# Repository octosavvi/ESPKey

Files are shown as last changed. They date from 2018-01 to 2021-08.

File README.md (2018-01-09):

### What the heck is this anyway?
ESPKey is a small device which can be implanted into facility access control systems.  ESPKey is compatible with pretty much every door that requires a card swipe or tap with optional pin code to unlock.  It even works on many systems requiring finger print or other biometric authentication.  Inserting an ESPKey behind a card reader is better than a skimmer because not only can it log all authorized use of a system, it can also inject or replay captured credentials.  Once ESPKey shows you what credentials work on this door, use your favorite RFID tools to clone or simulate those credentials for use on other doors.  Want to show someone how insecure their facility is?  This is an incredibly easy way to start.

In case you need a simple access control system to play with, ESPKey can do that too.  All you need is a card reader, ESPKey and some device to be controlled (like a door lock, electric strike, magnetic lock or just an indicator light).  ESPKey replaces the giant door controller, allowing you to build a simple mobile test lab.  Or a great little portable RFID credential sponge, ready to be hand carried or installed in any heavily trafficked area.

### Releases
Have a look [over here](https://github.com/octosavvi/ESPKey/releases/latest) for the latest pre-built firmware and UI release.

### Build instructions
Open in Arduino IDE and click Verify (or Upload if connected to UART).

### Usage
Check out [this great documentation](https://redteamtools.com/espkey) put together by Babak of Red Team Tools.

### Hardware
Hardware can be [purchased](https://redteamtools.com/espkey) or have a look in the [hardware](hardware/) directory if you want to build your own.

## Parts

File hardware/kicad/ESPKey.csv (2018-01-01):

Source: | ESPKey.sch
Date: | Thu 18 Aug 2016 11:03:30 PM PDT
Tool: | Eeschema 4.1.0-alpha+201607281303+6996~46~ubuntu16.04.1-product
Generator: | /usr/share/doc/kicad/scripts/bom-in-python/bom_csv_grouped_by_value_with_fp.py
Component Count: | 32
Ref | Qnty | Value | Cmp name | Footprint | Description | Vendor
C3, | 1 | np | C | Capacitors_SMD:C_0402 | Unpolarized capacitor
C4, C1, | 2 | 22u | C | Capacitors_SMD:C_0805 | Unpolarized capacitor
C5, C2, | 2 | 100n | C | Capacitors_SMD:C_0603 | Unpolarized capacitor
D1, | 1 | PWR | Led_Small | LEDs:LED_0603 | Led
L1, | 1 | 3.6uH | INDUCTOR_SMALL | Custom_Inductors:ELL4_M-small
P1, | 1 | Power | CONN_2 | Connector_IDC_SMD:SSL_DW_IDC_02
P2, | 1 | Wiegand | CONN_3 | Connector_IDC_SMD:SSL_DW_IDC_03
Q1, Q2, Q3, | 3 | 2N7002 | Q_NMOS_GSD | TO_SOT_Packages_SMD:SOT-23 | Transistor N-MOSFET (general)
R2, R1, | 2 | 75k | R | Resistors_SMD:R_0402 | Resistor
R3, | 1 | 24k | R | Resistors_SMD:R_0402 | Resistor
R6, R4, R5, R7, R8, R9, R10, R12, R13, R15, R16, | 11 | 12k7 | R | Resistors_SMD:R_0402 | Resistor
R11, R14, R17, | 3 | 22k | R | Resistors_SMD:R_0402 | Resistor
R18, | 1 | 330 | R | Resistors_SMD:R_0402 | Resistor
U1, | 1 | RT6212A/B | RT6212A/B | TO_SOT_Packages_SMD:SOT-23-6 | 700 mA Low Dropout Voltage Regulator, Adjustable 3.75V-30V, SO8
U2, | 1 | ESP-12 | ESP-12 | ESP8266:ESP-12-SMD | ESP8622 ESP-12 module, 16 pins, 2mm, PCB antenna

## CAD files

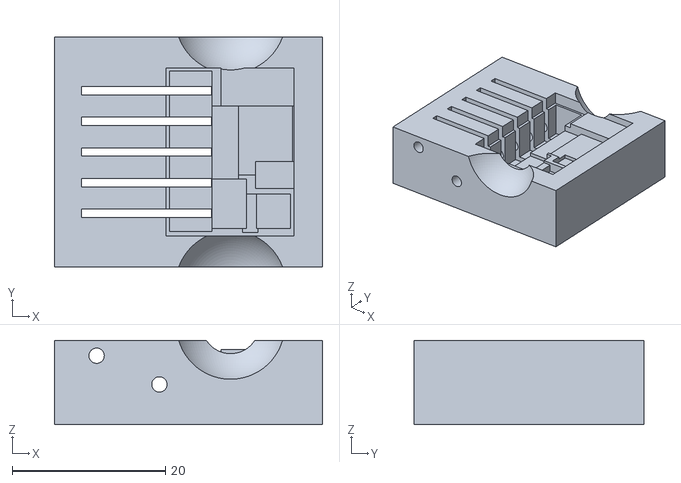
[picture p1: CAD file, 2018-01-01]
hardware/mechanical/programming-fixture.stl
35.0 x 30.0 x 11.0

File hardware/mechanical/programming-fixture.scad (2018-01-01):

$fn=100;
ff=0.5;
x=16.2;
y=21.5;
z=2.5;

module rc(rx, ry, rz, dx, dy, dz) {
    translate([
        (x/2*-1)+rx-(dx/2*-1),
        (y/2*-1)+ry-(dy/2*-1),
        (z/2*-1)+rz-(dz/2*-1)
    ]) cube([dx+ff, dy+ff, dz+ff], true);
}

module ESPKey() {
    difference() {
        union() {
            cube([x+ff,y+ff,z+ff], true);
            rc(.5,.4,z, 5,20.5,5.6);
            rc(x-4-.4,y-4-1,z, 4,4,1.6);
            rc(6,y-6-1,z, 4,6,1.6);
            rc(6,5,z, 3,9.5,1);
            rc(x-4.5,12.25,z, 4.5,3,1);
            rc(10,y-4.5-.5,z, 1.5,4.5,.4);
            rc(9,5,z, 7,8.5,.4);
        }
        translate([3.35+ff/2,-8.25-ff/2,0.85+ff/2]) 
            cube([9.5,5,0.8], true);
    }
}

difference() {
    fx=35;
    fy=30;
    fz=11;
    cube([fx, fy, fz], true);
    zoff=fz/2-(2.5+ff)/2+1;
    translate([5.4,0,zoff]) rotate([180,0,0]) ESPKey();

    //piano-wire trenches
    translate([-5.5,-8,0]) cube([17,1.1,fz+1], true);
    translate([-5.5,-4,0]) cube([17,1.1,fz+1], true);
    translate([-5.5,0,0]) cube([17,1.1,fz+1], true);
    translate([-5.5,4,0]) cube([17,1.1,fz+1], true);
    translate([-5.5,8,0]) cube([17,1.1,fz+1], true);
    
    //toothpick holes
    translate([-3.8,15,zoff-5.25]) rotate([90,0,0]) cylinder(30,r=1,true);
    translate([-12,15,zoff-1.5]) rotate([90,0,0]) cylinder(30,r=1,true);

    //piano-wire holes
    translate([-10,-8,zoff-0.5]) rotate([0,270,0]) cylinder(10,d=1,true);
    translate([-10,-4,zoff-0.5]) rotate([0,270,0]) cylinder(10,d=1,true);
    translate([-10,0,zoff-0.5]) rotate([0,270,0]) cylinder(10,d=1,true);
    translate([-10,4,zoff-0.5]) rotate([0,270,0]) cylinder(10,d=1,true);
    translate([-10,8,zoff-0.5]) rotate([0,270,0]) cylinder(10,d=1,true);

    //finger holes
    translate([5.5,-17.5,zoff+2.5]) sphere(d=15);
    translate([5.5,17.5,zoff+2.5]) sphere(d=15);
}

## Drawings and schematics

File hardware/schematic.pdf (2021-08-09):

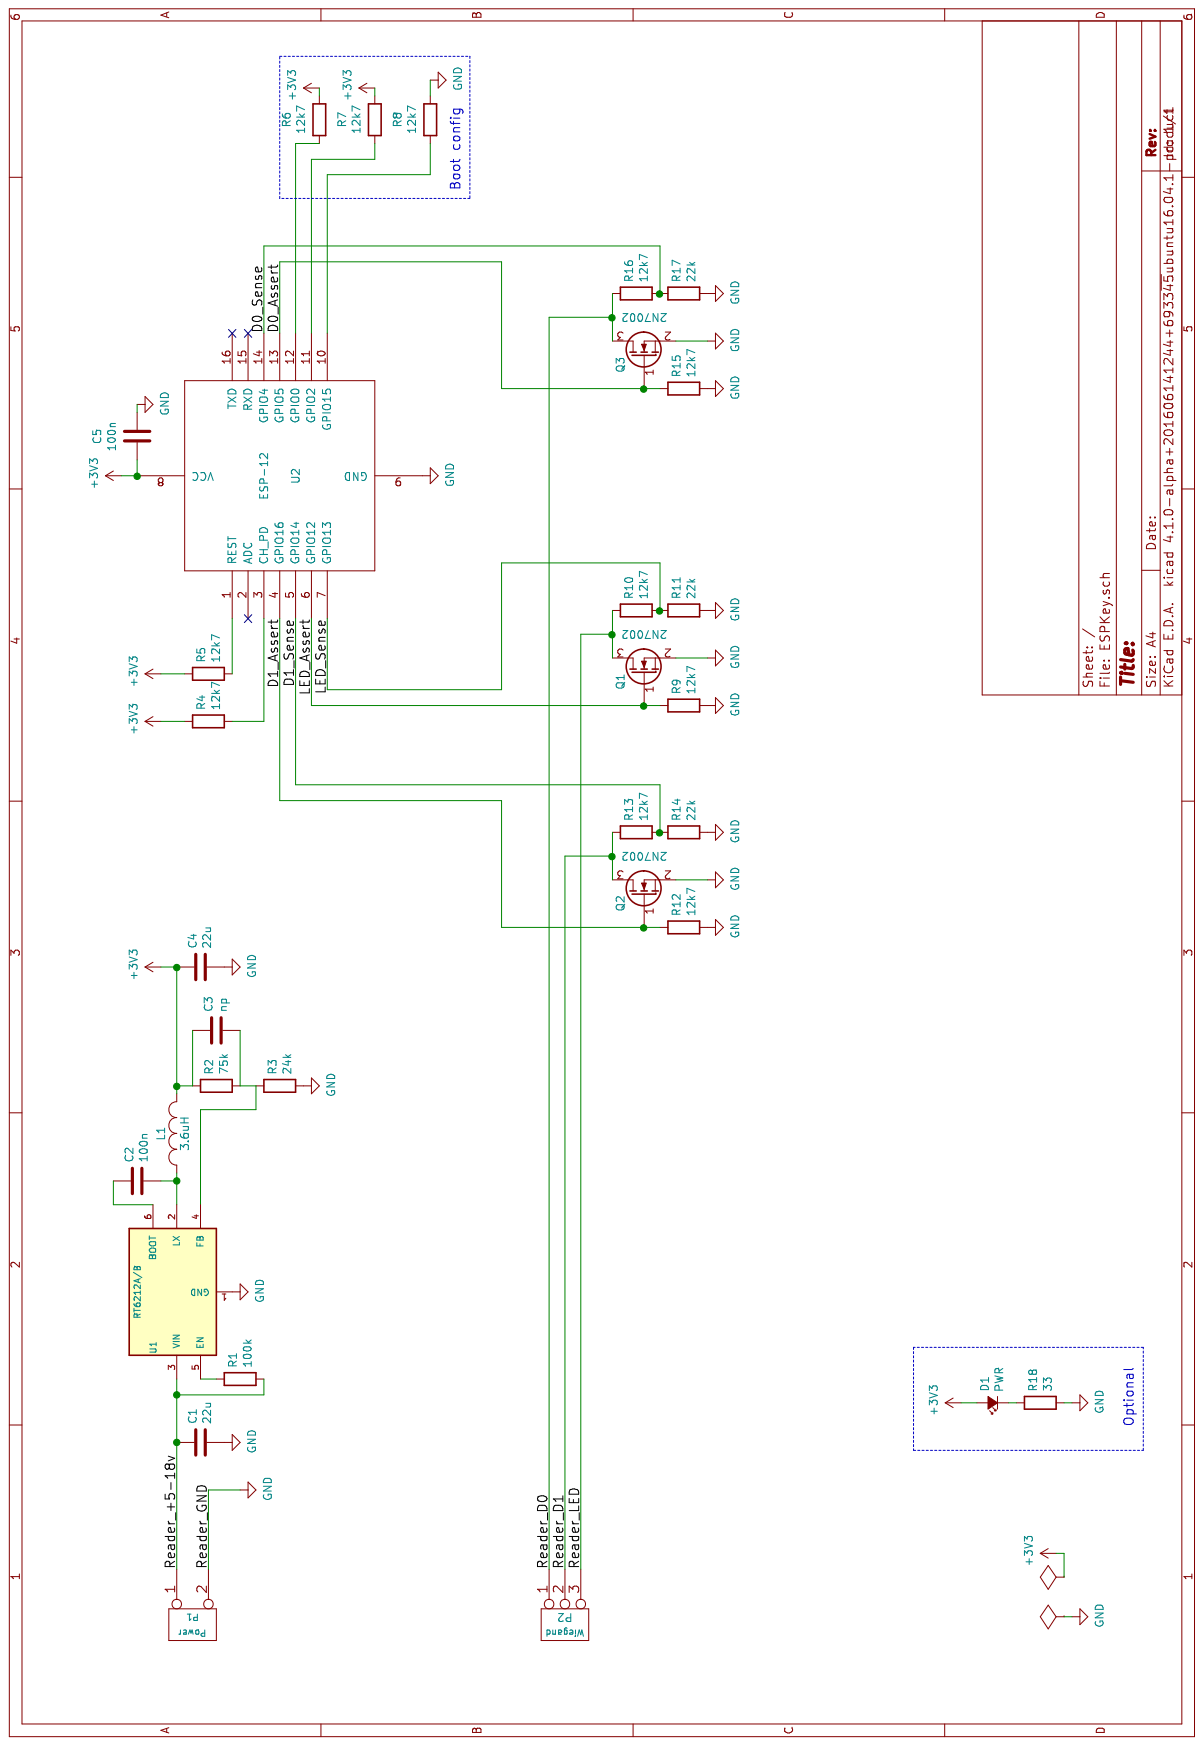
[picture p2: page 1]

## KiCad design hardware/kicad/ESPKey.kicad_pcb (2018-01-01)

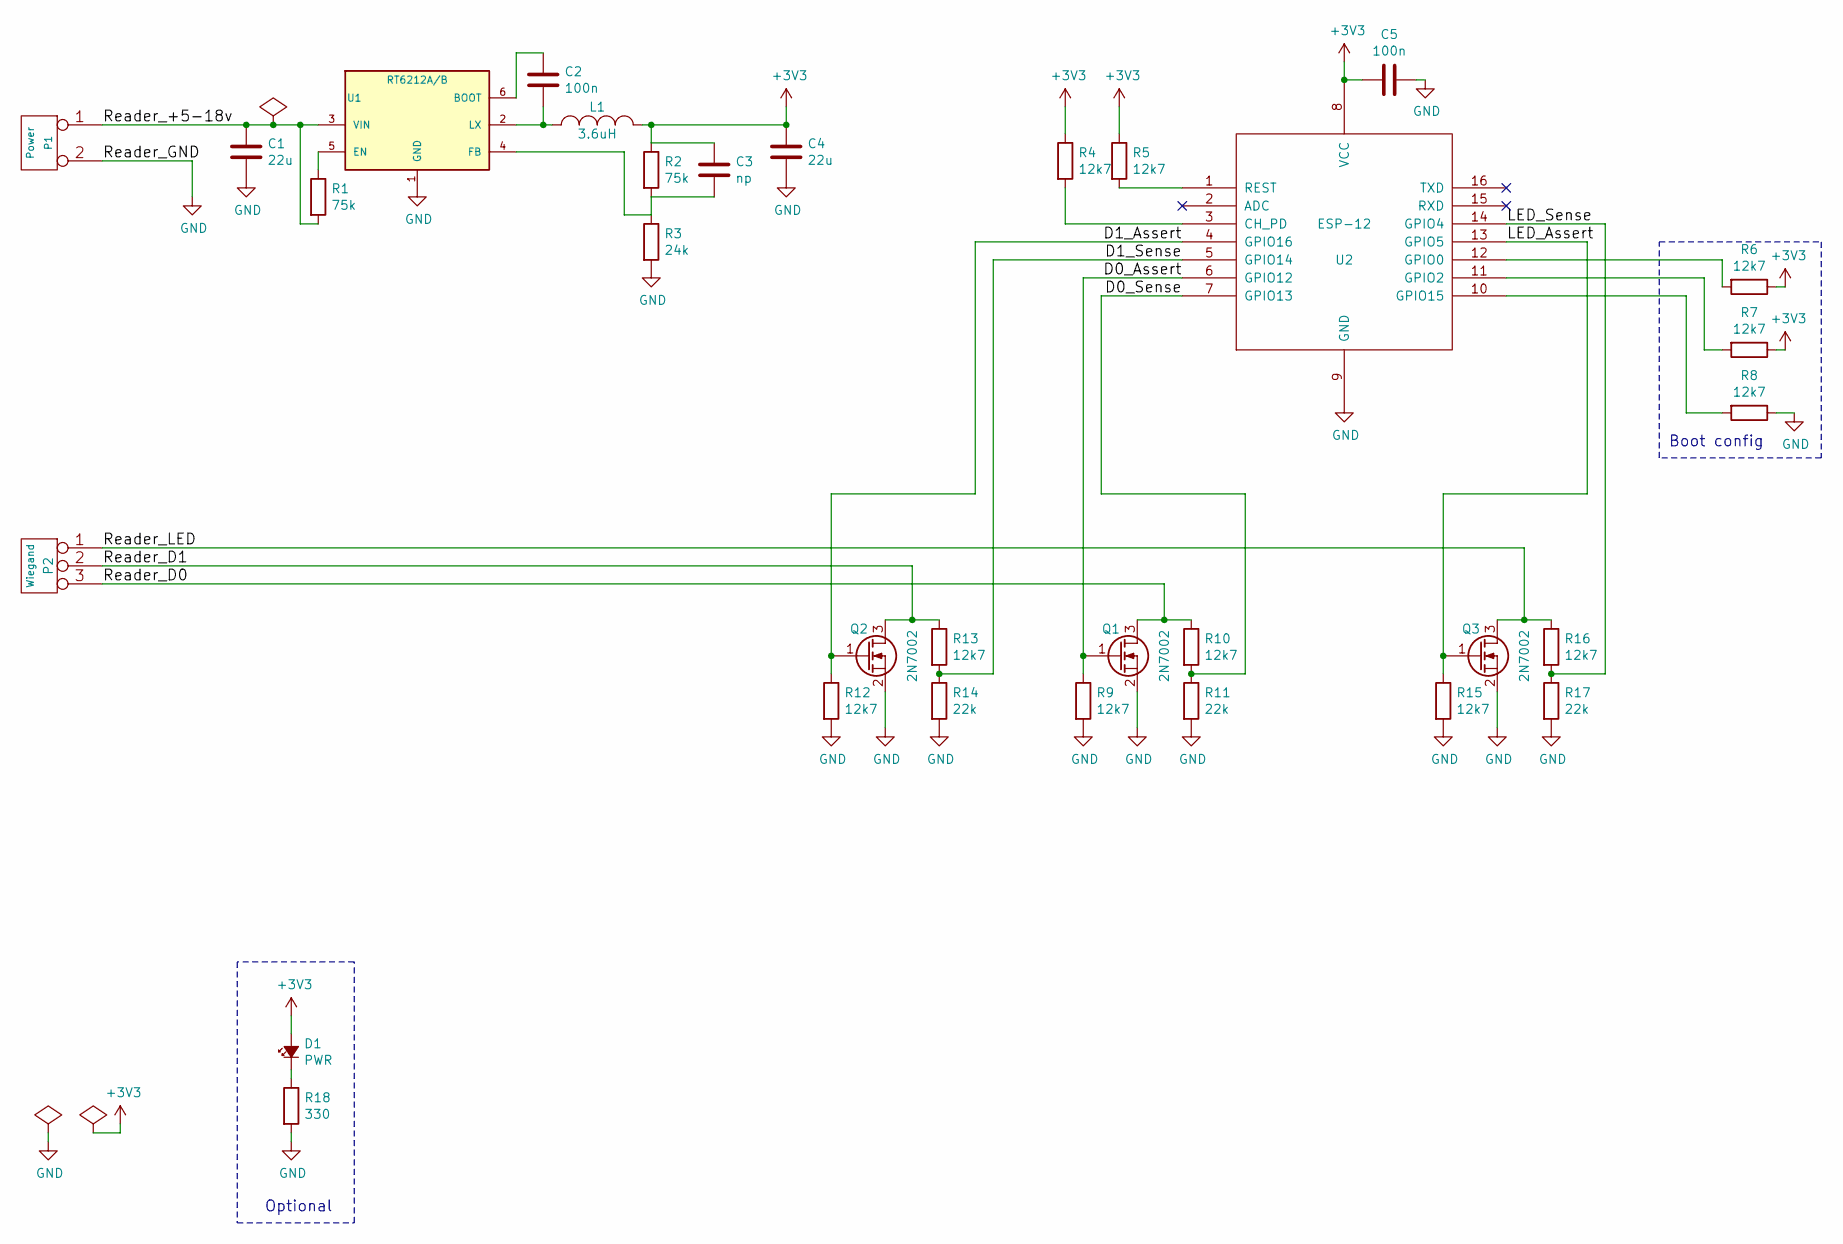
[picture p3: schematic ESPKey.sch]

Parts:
C1, C4: 22u; C_0805
C2, C5: 100n; C_0603
C3: np; C_0402
D1: PWR; LED_0603
L1: 3.6uH; ELL4_M-small
P1: Power; SSL_DW_IDC_02
P2: Wiegand; SSL_DW_IDC_03
Q1, Q2, Q3: 2N7002; SOT-23
R1, R2: 75k; R_0402
R3: 24k; R_0402
R4, R5, R6, R7, R8, R9, R10, R12, R13, R15, R16: 12k7; R_0402
R11, R14, R17: 22k; R_0402
R18: 330; R_0402
U1: RT6212A/B; SOT-23-6
U2: ESP-12; ESP-12-SMD

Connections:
+3V3: C3.2, C4.2, C5.2, D1.2 (A), L1.2, R2.1, R4.1, R5.1, R6.1, R7.1, U2.8 (VCC)
/D0_Assert: Q1.1 (G), R9.1, U2.6 (GPIO12)
/D0_Sense: R10.2, R11.1, U2.7 (GPIO13)
/D1_Assert: Q2.1 (G), R12.1, U2.4 (GPIO16)
/D1_Sense: R13.2, R14.1, U2.5 (GPIO14)
/LED_Assert: Q3.1 (G), R15.1, U2.13 (GPIO5)
/LED_Sense: R16.2, R17.1, U2.14 (GPIO4)
/Reader_+5-18v: C1.2, P1.1, R1.2, U1.3 (VIN)
/Reader_D0: P2.3, Q1.3 (D), R10.1
/Reader_D1: P2.2 (PM), Q2.3 (D), R13.1
/Reader_LED: P2.1, Q3.3 (D), R16.1
GND: C1.1, C4.1, C5.1, P1.2 (PM), Q1.2 (S), Q2.2 (S), Q3.2 (S), R3.2, R8.1, R9.2, R11.2, R12.2, R14.2, R15.2, R17.2, R18.2, U1.1 (GND), U2.9 (GND)
unnamed: C2.1, L1.1, U1.2 (LX)
unnamed: C2.2, U1.6 (BOOT)
unnamed: C3.1, R2.2, R3.1, U1.4 (FB)
unnamed: D1.1 (K), R18.1
unnamed: R1.1, U1.5 (EN)
unnamed: R4.2, U2.3 (CH_PD)
unnamed: R5.2, U2.1 (REST)
unnamed: R6.2, U2.12 (GPIO0)
unnamed: R7.2, U2.11 (GPIO2)
unnamed: R8.2, U2.10 (GPIO15)

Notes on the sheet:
Boot config
Optional

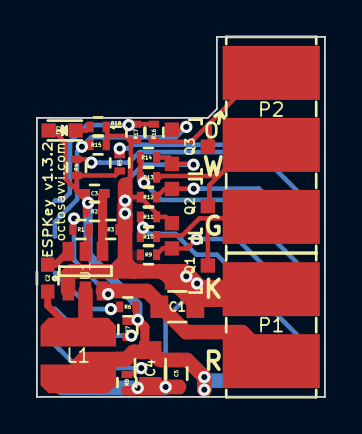
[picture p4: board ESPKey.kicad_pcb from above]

Board: 2 copper layers, 16.0 x 20.0 mm, 32 parts (1 on the bottom side), 22 nets.

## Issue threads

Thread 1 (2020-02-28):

Schematics in pdf

piotrva, 2020-02-28:
Please add schematics in pdf or other universal format - now in order to view the schematic you need to download KiCad...

Dan-Rdd, 2021-07-17:
Use EasyEDA you can import the kicad design and get everything :)

Dan-Rdd, 2021-07-17:
> Please add schematics in pdf or other universal format - now in order to view the schematic you need to download KiCad...

Use EasyEDA you can import the kicad design and get everything :)

piotrva, 2021-07-18:
Well, still it requires you to download it, and do some operations - nearly all other hardware I see on github has a pdf or graphic format of schematic.

piotrva, 2021-07-18:
Also it requires the user to register to EasyEDA- definitely not a handy thing...

piotrva, 2021-07-18:
[Schematic_espkey_2021-07-18.pdf](https://github.com/octosavvi/ESPKey/files/6836575/Schematic_espkey_2021-07-18.pdf)

Dan-Rdd, 2021-07-19:
Im finding it hard to find parts based on the bom

aSmig, 2021-08-09:
This was clearly an oversight on my part. Sorry for the hassle and thanks for finding your own way in the interim. Added in https://github.com/octosavvi/ESPKey/commit/e7455d395015cc0b97b9b0d487159943da6d5e61

Closed 2021-08-09.

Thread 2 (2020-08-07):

Source for IDC connectors?

BuckarewBanzai, 2020-08-07:
Does anyone have a source for the 2 IDC connectors and/or what the suggested wire gauge would be?

"P1, ","1","Power","CONN_2","Connector_IDC_SMD:SSL_DW_IDC_02","",""
"P2, ","1","Wiegand","CONN_3","Connector_IDC_SMD:SSL_DW_IDC_03","",""

0xDezzy, 2020-09-15:
You can find the IDC connectors and punch down bit here: https://www.mouser.com/Search/Refine?Ntk=P_MarCom&Ntt=163398077

Dan-Rdd, 2021-07-19:
> You can find the IDC connectors and punch down bit here: https://www.mouser.com/Search/Refine?Ntk=P_MarCom&Ntt=163398077

thank you

aSmig, 2021-08-08:
The AVX part numbers 009176002022006 (2-position) and 009176003022006 (3-position) are available through DigiKey, Mouser, Newark, Arrow, etc. These parts are designed for 22 AWG stranded wire but variants are available for 18 AWG through 24 AWG if your target site is using these sizes. 22 AWG seems to be the most common.

Closed 2021-08-08.

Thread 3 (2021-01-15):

Compilation Fails (overloaded string)

shadeunicorns, 2021-01-15:
Line 299 | DBG_OUTPUT_PORT.println("Loaded syslog_server: " + String(syslog_server, HEX));

causes an error with
"exit status 1
call of overloaded 'String(IPAddress&, int)' is ambiguous"

if that entire IF statement is removed the code compiles, is it mandatory to have this statement? and if so please provide a patch or instructions on how to solve this.

mick-EOMFD, 2021-09-14:
I've downgraded both the Arduino IDE to 1.8.5, and ArduinoJson to 5.13.2 but for some reason it's still calling out line 299 as ambiguous. I've also tried ArduinoJson 5.11 and a few older versions of the Arduino IDE but any thoughts or suggestions would be greatly appreciated!
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

aSmig, 2021-09-30:
@mick-EOMFD, it looks like there is an issue with esp8266 3.0.2 working with the older IDE 1.8.5. Try opening the board manager and downgrading esp8266 to something in the 2.x.x family.

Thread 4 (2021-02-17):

ESP8266 - Revision?

CyberCityCircuits, 2021-02-17:
Could you tell me what revision of the ESP8266 the retail version of this was built with?  I have the 12-E and 12-F and neither have the external antenna connection.

shadeunicorns, 2021-03-12:
I ordered a run of 12f versions and they worked fine.
the version shown off on LPL and avalible through Redteamtools uses the esp-07 variant. however i ordered the 12f versions to avoid needing to connect an external u.fl antenna

aSmig, 2021-08-08:
The retail version includes a custom ESP-07 with increased capacity SPI Flash. The ESP-07 usually has 1 MB flash but ESPKey ships with 4 MB for increased logging capacity. As detailed elsewhere the ESP-07 includes a chip antenna. I've found that the on-board chip antenna performs well for most installations and have only needed to add an external antenna via U.FL when installing the module inside of a fully enclosed metal box. Even in a metal box, short range connections are often possible.

Closed 2021-08-08.

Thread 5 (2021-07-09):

Extra features

TimCarrDP, 2021-07-09:
Im aware this hasn't been updated in a while, but possibly might be worth adding RS232 logging too.

aSmig, 2021-08-08:
I'd love to see some pull requests for logging other protocols. RS232 would require some hardware mods on the ESPKey due to the higher voltages for that standard. 5V UART could be logged without hardware modification. I've done a little bit of tinkering with logging I2C and UART using the ESPKey but haven't come up with a user interface, so nothing worth sharing.

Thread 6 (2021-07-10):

Comple error for ArduinoJson 6

dbuggz, 2021-07-10:
Hi,
just looking into your ESPKey and when I compile the ESPKey.ino I get:

`ESPKey:238:11: error: StaticJsonBuffer is a class from ArduinoJson 5. Please see https://arduinojson.org/upgrade to learn how to upgrade your program to ArduinoJson version 6
  238 |   StaticJsonBuffer<1024> jsonBuffer;
      |           ^~~~~~~~~~~~~~~~~~~~~~~~~~                 `

I've tried a couple of things from their page ( changing the JsonBuffer in line 238 and removing the & in line 239) but am not proficient enough to work all the changes out.

aSmig, 2021-08-08:
You may find it easier to use the Arduino library manager to downgrade your ArduinoJson rather than updating the code to work with ArduinoJson 6. The last release was compiled with ArduinoJson 5.11 but more recent versions in the 5.x family are likely to work too.

To open the library manager: Sketch -> Include Library -> Manage Libraries...
To downgrade: search for ArduinoJson, click on it, a "Select Version" drop-down box will appear, choose a version and press Install

Closed 2021-08-08.

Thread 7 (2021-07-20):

Up to date Bom

Dan-Rdd, 2021-07-20:
Would anyone be willing to upload an up to date bom I'm finding it hard to source all components from a single supplier

hitriy, 2021-08-29:
Actually it's quite easy to find all the details from one supplier except RT6212A/B dc-dc converter. Seems it's easier to redraw schematics with alternative conveter, than waiting for RT6212A/B will be accessible for reasonalbe price.

aSmig, 2021-09-01:
Looks like DigiKey still has the [SMPS](https://www.digikey.com/en/products/detail/richtek-usa-inc/RT6212CHGJ6F/7383402) and reasonable substitutions for everything but the ESP module. I always had to source the ESP separately during development.

Dan-Rdd, 2021-09-01:
awesome thank you both :)

aSmig, 2021-09-01:
I have lots of complaints about DigiKey BOM management. My past orders and old BOM from when I was developing this project are gone. Presumably due to system updates and the new list manager replacing the old BOM manager. Public list sharing is still not possible as far as I can tell. So here is a list of parts that look like they should work (untested):

| Quantity | Digi-Key Part Number | Description | Reference |
|---|---|---|---|
| 1 | 478-4615-1-ND | CONN SSL IDC CONTACT 22AWG SLDR | P1 |
| 1 | 478-4619-1-ND | CONN SSL IDC CONTACT 22AWG SLDR | P2 |
| 1 | RT6212CHGJ6FCT-ND | IC REG BUCK ADJ 2A TSOT23-6 | U1 |
| 1 | P330JCT-ND | RES SMD 330 OHM 5% 1/10W 0402 | R18 |
| 3 | P22.0KLCT-ND | RES SMD 22K OHM 1% 1/10W 0402 | R11, R14, R17 |
| 11 | P12.7KLCT-ND | RES SMD 12.7K OHM 1% 1/10W 0402 | R4-10, R12-13, R15-16 |
| 1 | 10-ERJ-U02F2402XCT-ND | RES 24K OHM 1% 1/10W 0402 SMD | R3 |
| 2 | 10-ERJ-U02F7502XCT-ND | RES 75K OHM 1% 1/10W 0402 SMD | R1-2 |
| 3 | 1727-4692-1-ND | MOSFET N-CH 60V 360MA TO236AB | Q1-3 |
| 1 | 732-1007-1-ND | FIXED IND 3.6UH 1.38A 85MOHM SMD | L1 |
| 2 | 1276-CL10B104KB8VPJCCT-ND | CAP CER 100NF 50V X7R 0603 | C2, C5 |
| 2 | 1276-CL21A226MAYNNNECT-ND | MLCC22UF25V 20 X5R0805 | C1, C4 |
| 1 | 1830-1061-1-ND | LED BLUE CLEAR 0603 SMD | D1 |

I recommend bringing up the power supply first and validating that the inductor and feedback resistors (R2 and R3) provide clean, 3.3V. Good luck!

Dan-Rdd, 2021-09-01:
fantastic aSmig thank you

Dan-Rdd, 2021-09-02:
Looking at the design seems to have afew shorts or is this how it is to be designed??
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

aSmig, 2021-09-02:
Yeah, those shorts would definitely cause problems. Your footprint pads for the ESP are oversized. Looks like your ground fill clearance is much tighter too. Here is a capture from gerbv with the gerbers in this repo:
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

Closed 2021-09-01.

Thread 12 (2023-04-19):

Kantech XSF

zzzzzzzzzzzzzzzzzzzzzzzzzzzzzzzzzzzzz-z, 2023-04-19:
Any comments on usability for P325XSF reader?
It supports dual 26-bit Wiegand or Kantech XSF format, is this for the data cable or card reader, possible support for this?

aSmig, 2023-04-23:
Kantech XSF is used between the card and the card reader. Since ESPKey is installed between the card reader and the door controller, only the wired protocol matters. Looking at images of the P325XSF, I see the only data connections are labeled D0 and D1, which indicates standard Wiegand protocol. ESPKey will almost certainly work with this reader.

zzzzzzzzzzzzzzzzzzzzzzzzzzzzzzzzzzzzz-z, 2023-04-23:
@aSmig Yes i know, one particular thing im interested in the WieGand26 Protocol is a backend protocol to the CNC, while XSF is also an backend controller signal format together with ExtraPass control software from Kantech. As shown in blueprint of the reader circuit a switch for XSF/WieGand26 is visible in the backend of the card reader, i suspect since Wiegand is not a card format and only used in the backend of the reader could XSF also be another ‘secure’ format for communicating with the entire Kantech ecosystem?

Closed 2023-04-23.

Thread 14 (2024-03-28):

Missing KiCAD libraries

nuschpl, 2024-03-28:
Hello
I'm getting to the following when trying to open schematics:
```
The following libraries were not found:
power.lib
device.lib
transistors.lib
conn.lib
linear.lib
regul.lib
74xx.lib
cmos4000.lib
adc-dac.lib
memory.lib
xilinx.lib
microcontrollers.lib
dsp.lib
microchip.lib
analog_switches.lib
motorola.lib
texas.lib
intel.lib
audio.lib
interface.lib
digital-audio.lib
philips.lib
display.lib
cypress.lib
siliconi.lib
opto.lib
atmel.lib
contrib.lib
valves.lib
libraries/Richtek/Richtek.lib
libraries/kicad-ESP8266/ESP8266.lib
```
Are there any references to exact source of those libraries ? And are all those in deed needed(I see mulitple vendors) , if not can those be removed ?

aSmig, 2024-04-24:
I recommend using the [Schematic PDF](https://github.com/octosavvi/ESPKey/blob/master/hardware/schematic.pdf) rather than trying to open this old dead project in modern Eeschema.

This error looks like a version mismatch issue. KiCad of 7 years ago included most of the listed libraries as default (the two exceptions are Richtek and ESP8266). Why it chose to explicitly list all of those default libraries in the project file is beyond me. None of these library files should be necessary to open the project because all non-standard parts used in the project were automatically duplicated into the ESPKey-cache.lib file.

Sources for reference:
[ESP8266.lib](https://github.com/jdunmire/kicad-ESP8266)
Richtek.lib unknown - maybe I cobbled it together. The only part it contains is already in ESPKey-cache.lib

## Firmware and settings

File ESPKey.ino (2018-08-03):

/* ESPKey
*  Kenny McElroy
*
* This sketch runs on the ESPKey ESP8266 module carrier with the 
* intent of being physically attached to the Wiegand data wires
* between a card reader and the local control box.
* 
* Huge thanks to Brad Antoniewicz for sharing his Wiegand tools
* for Arduino.  This code was a great starting point and
* excellent reference: https://github.com/brad-anton/VertX
*
*/

#include <ESP8266WiFi.h>
#include <WiFiUdp.h>
#include <WiFiClient.h>
#include <ESP8266WebServer.h>
#include <ESP8266mDNS.h>
#include <ESP8266HTTPUpdateServer.h>
#include <FS.h>
#include <ArduinoOTA.h>
#include <ArduinoJson.h>

#ifdef ESP8266
extern "C" {
  #include "user_interface.h"
}
#endif

#define VERSION "131"

#define HOSTNAME "ESPKey-" // Hostname prefix for DHCP/OTA
#define CONFIG_FILE "/config.json"
#define AUTH_FILE "/auth.txt"
#define DBG_OUTPUT_PORT Serial	// This could be a file with some hacking
#define CARD_LEN 4     // minimum card length in bits
#define PULSE_WIDTH 34 // length of asserted pulse in microSeconds
#define PULSE_GAP 2000 - PULSE_WIDTH   // delay between pulses in microSeconds

// Pin number assignments
#define D0_ASSERT 12
#define D0_SENSE 13
#define D1_ASSERT 16
#define D1_SENSE 14
#define LED_ASSERT 4
#define LED_SENSE 5
#define CONF_RESET 0

// Default settings used when no configuration file exists
char log_name[20] = "Alpha";
bool ap_enable = true;
bool ap_hidden = false;
char ap_ssid[20] = "ESPKey-config"; // Default SSID.
IPAddress ap_ip(192, 168, 4, 1);
char ap_psk[20] = "accessgranted"; // Default PSK.
char station_ssid[20] = "";
char station_psk[20] = "";
char mDNShost[20] = "ESPKey";
String DoS_id = "7fffffff:31";
char ota_password[24] = "ExtraSpecialPassKey";
char www_username[20] = "";
char www_password[20] = "";
IPAddress syslog_server(0, 0, 0, 0);
unsigned int syslog_port = 514;
char syslog_service_name[20] = "accesscontrol";
char syslog_host[20] = "ESPKey";
byte syslog_priority = 36;

WiFiUDP Udp;
ESP8266WebServer server(80);
ESP8266HTTPUpdateServer httpUpdater;
File fsUploadFile;

//byte incoming_byte = 0; 
unsigned long config_reset_millis = 30000;
byte reset_pin_state = 1;

volatile byte reader1_byte = 0;
String reader1_string = "";
volatile int reader1_count = 0;
volatile unsigned long reader1_millis = 0;
volatile unsigned long last_aux_change = 0;
volatile byte last_aux = 1;
volatile byte expect_aux = 2;

void reader1_append(int value) {
  reader1_count++;
  reader1_millis = millis();
  reader1_byte = reader1_byte << 1;
  reader1_byte |= 1 & value;
  if (reader1_count % 4 == 0) {
    reader1_string += String(reader1_byte, HEX);
    reader1_byte = 0;
  }
}

void reader1_D0_trigger(void) {
  reader1_append(0);
}

void reader1_D1_trigger(void) {
  reader1_append(1);
}

byte hex_to_byte(byte in) {
  if (in>='0' && in<='9') return in-'0';
  else if (in>='A' && in<='F') return in-'A'+10;
  else if (in>='a' && in<='f') return in-'a'+10;
  else return in;
}

char c2h (unsigned char c) {
  //DBG_OUTPUT_PORT.println("c2h: " + String(c));
  return "0123456789abcdef"[0xF & c];
}

void fix_reader1_string() {
  byte loose_bits = reader1_count % 4;
  if (loose_bits > 0) {
    byte moving_bits = 4 - loose_bits;
    byte moving_mask = pow(2, moving_bits) - 1;
    //DBG_OUTPUT_PORT.println("lb: " + String(loose_bits) + " mb: " + String(moving_bits) + " mm: " + String(moving_mask, HEX));
    char c = hex_to_byte(reader1_string.charAt(0));
    for (unsigned long i=0; i<reader1_string.length(); i++) {
      reader1_string.setCharAt(i, c2h(c >> moving_bits));
      c &= moving_mask;
      c = (c << 4) | hex_to_byte(reader1_string.charAt(i+1));
      //DBG_OUTPUT_PORT.println("c: " + String(c, HEX) + " i: " + String(reader1_string.charAt(i)));
    }
    reader1_string += String((c >> moving_bits) | reader1_byte, HEX);
  }
  reader1_string += ":" + String(reader1_count);
}

void reader1_reset() {
  reader1_byte = 0;
  reader1_count = 0;
  reader1_string = "";
}

void drainD0(){
  digitalWrite(D0_ASSERT, HIGH);
}

byte toggle_pin(byte pin) {
  byte new_value = !digitalRead(pin);
  if (pin == LED_ASSERT) expect_aux = !new_value;
  digitalWrite(pin, new_value);
  return new_value;
}

void transmit_assert(byte pin) {
  digitalWrite(pin, HIGH);
  delayMicroseconds(PULSE_WIDTH);
  digitalWrite(pin, LOW);
  delayMicroseconds(PULSE_GAP);
}

void transmit_id_nope(volatile unsigned long sendValue, unsigned short bitcount) {
  DBG_OUTPUT_PORT.println("[-] Sending Data: " + String(sendValue, HEX) + ":" + String(bitcount));
  DBG_OUTPUT_PORT.print("\t");
  for (short x=bitcount-1; x>=0; x--) {
    byte v = bitRead(sendValue,x);
    DBG_OUTPUT_PORT.print(String(v)); 
    if (v == 0) {
      transmit_assert(D0_ASSERT);
    } else {
      transmit_assert(D1_ASSERT);
    }
  }
  DBG_OUTPUT_PORT.println();
}

void transmit_id(String sendValue, unsigned long bitcount) {
  DBG_OUTPUT_PORT.println("Sending data: " + sendValue + ":" + String(bitcount));
  unsigned long bits_available = sendValue.length() * 4;
  unsigned long excess_bits = 0;
  if (bits_available > bitcount) {
    excess_bits = bits_available - bitcount;
    sendValue = sendValue.substring(excess_bits/4);
    excess_bits %= 4;
    //DBG_OUTPUT_PORT.print("sending: " + sendValue + " with excess bits: " + excess_bits + "\n\t");
  } else if (bits_available < bitcount) {
    for (unsigned long i = bitcount - bits_available; i>0; i--) {
      transmit_assert(D0_ASSERT);
    }
  }
  for (unsigned long i=0; i<sendValue.length(); i++) {
    char c = hex_to_byte(sendValue.charAt(i));
    //DBG_OUTPUT_PORT.println("i:" + String(i) + " c:0x" + String(c,HEX));
    for (short x=3-excess_bits; x>=0; x--) {
      byte b = bitRead(c,x);
      //DBG_OUTPUT_PORT.println("x:" + String(x) + " b:" + b);
      if (b == 1) {
        transmit_assert(D1_ASSERT);
      } else {
        transmit_assert(D0_ASSERT);
      }
    }
    excess_bits = 0;
  }
  //DBG_OUTPUT_PORT.println();
}

void handleTxId(){
  if(!server.hasArg("v")) {server.send(500, F("text/plain"), F("BAD ARGS")); return;}
  String value = server.arg("v");
  //DBG_OUTPUT_PORT.println("handleTxId: " + value);
  String sendValue = value.substring(0, value.indexOf(":"));
  sendValue.toUpperCase();
  unsigned long bitcount = value.substring(value.indexOf(":") + 1).toInt();
  transmit_id(sendValue, bitcount);
  
  server.send(200, F("text/plain"), "");
}

bool loadConfig() {
  File configFile = SPIFFS.open(CONFIG_FILE, "r");
  if (!configFile) {
    DBG_OUTPUT_PORT.println(F("Failed to open config file"));
    return false;
  }

  size_t size = configFile.size();
  if (size > 1024) {
    DBG_OUTPUT_PORT.println(F("Config file size is too large"));
    return false;
  }

  // Allocate a buffer to store contents of the file.
  std::unique_ptr<char[]> buf(new char[size]);

  // We don't use String here because ArduinoJson library requires the input
  // buffer to be mutable. If you don't use ArduinoJson, you may as well
  // use configFile.readString instead.
  configFile.readBytes(buf.get(), size);

  StaticJsonBuffer<1024> jsonBuffer;
  JsonObject& json = jsonBuffer.parseObject(buf.get());

  if (!json.success()) {
    DBG_OUTPUT_PORT.println(F("Failed to parse config file"));
    return false;
  }

  // FIXME these should be testing for valid input before replacing defaults
  if (json.containsKey("log_name")) {
    strncpy(log_name, json["log_name"], 20);
    DBG_OUTPUT_PORT.println("Loaded log_name: " + String(log_name));
  }
  if (json.containsKey("ap_enable")) {
    ap_enable = (strcmp(json["ap_enable"], "true") == 0) ? true : false;
    DBG_OUTPUT_PORT.println("Loaded ap_enable: " + String(ap_enable));
  }
  if (json.containsKey("ap_hidden")) {
    ap_hidden = (strcmp(json["ap_hidden"], "true") == 0) ? true : false;
    DBG_OUTPUT_PORT.println("Loaded ap_hidden: " + String(ap_hidden));
  }
  if (json.containsKey("ap_ssid")) {
    strncpy(ap_ssid, json["ap_ssid"], 20);
    DBG_OUTPUT_PORT.println("Loaded ap_ssid: " + String(ap_ssid));
  }
  if (json.containsKey("ap_psk")) {
    strncpy(ap_psk, json["ap_psk"], 20);
    DBG_OUTPUT_PORT.println("Loaded ap_psk: " + String(ap_psk));
  }
  if (json.containsKey("station_ssid")) {
    strncpy(station_ssid, json["station_ssid"], 20);
    DBG_OUTPUT_PORT.println("Loaded station_ssid: " + String(station_ssid));
  }
  if (json.containsKey("station_psk")) {
    strncpy(station_psk, json["station_psk"], 20);
    DBG_OUTPUT_PORT.println("Loaded station_psk: " + String(station_psk));
  }
  if (json.containsKey("mDNShost")) {
    strncpy(mDNShost, json["mDNShost"], 20);
    DBG_OUTPUT_PORT.println("Loaded mDNShost: " + String(mDNShost));
  }
  if (json.containsKey("DoS_id")) {
    DoS_id = String((const char*)json["DoS_id"]);
    DBG_OUTPUT_PORT.println("Loaded DoS_id: " + DoS_id);
  }
  if (json.containsKey("ota_password")) {
    strncpy(ota_password, json["ota_password"], 24);
    DBG_OUTPUT_PORT.println("Loaded ota_password: " + String(ota_password));
  }
  if (json.containsKey("www_username")) {
    strncpy(www_username, json["www_username"], 20);
    DBG_OUTPUT_PORT.println("Loaded www_username: " + String(www_username));
  }
  if (json.containsKey("www_password")) {
    strncpy(www_password, json["www_password"], 20);
    DBG_OUTPUT_PORT.println("Loaded www_password: " + String(www_password));
  }
  if (json.containsKey("syslog_server")) {
    char buf[20];
    strncpy(buf, json["syslog_server"], 20);
    syslog_server.fromString(buf);
    DBG_OUTPUT_PORT.println("Loaded syslog_server: " + String(syslog_server, HEX));
  }
  if (json.containsKey("syslog_port")) {
    syslog_port = json["syslog_port"];
    DBG_OUTPUT_PORT.println("Loaded syslog_port: " + String(syslog_port));
  }
  if (json.containsKey("syslog_service_name")) {
    strncpy(syslog_service_name, json["syslog_service_name"], 20);
    DBG_OUTPUT_PORT.println("Loaded syslog_service_name: " + String(syslog_service_name));
  }
  if (json.containsKey("syslog_host")) {
    strncpy(syslog_host, json["syslog_host"], 20);
    DBG_OUTPUT_PORT.println("Loaded syslog_host: " + String(syslog_host));
  }
  if (json.containsKey("syslog_priority")) {
    syslog_priority = json["syslog_priority"];
    DBG_OUTPUT_PORT.println("Loaded syslog_priority: " + String(syslog_priority));
  }

  return true;
}

//format bytes
String formatBytes(size_t bytes){
  if (bytes < 1024){
    return String(bytes)+"B";
  } else if(bytes < (1048576)){
    return String(bytes/1024.0)+"KB";
  } else if(bytes < (1073741824)){
    return String(bytes/1048576.0)+"MB";
  } else {
    return String(bytes/1073741824.0)+"GB";
  }
}

String getContentType(String filename){
  if(server.hasArg("download")) return F("application/octet-stream");
  else if(filename.endsWith(".htm")) return F("text/html");
  else if(filename.endsWith(".html")) return F("text/html");
  else if(filename.endsWith(".css")) return F("text/css");
  else if(filename.endsWith(".js")) return F("application/javascript");
  else if(filename.endsWith(".json")) return F("text/json");
  else if(filename.endsWith(".png")) return F("image/png");
  else if(filename.endsWith(".gif")) return F("image/gif");
  else if(filename.endsWith(".jpg")) return F("image/jpeg");
  else if(filename.endsWith(".ico")) return F("image/x-icon");
  else if(filename.endsWith(".svg")) return F("image/svg+xml");
  else if(filename.endsWith(".xml")) return F("text/xml");
  else if(filename.endsWith(".pdf")) return F("application/x-pdf");
  else if(filename.endsWith(".zip")) return F("application/x-zip");
  else if(filename.endsWith(".gz")) return F("application/x-gzip");
  return "text/plain";
}

void append_log(String text) {
  File file = SPIFFS.open("/log.txt", "a");
  if(file) {
    file.println(String(millis()) + " " + text);
    DBG_OUTPUT_PORT.println("Appending to log: " + String(millis()) + " " + text);
    file.close();
  }
  else
    DBG_OUTPUT_PORT.println("Failed opening log file.");
}

void syslog(String text) {
  if (WiFi.status() != WL_CONNECTED || syslog_server == INADDR_NONE) return;
  char buf[101];
  text = "<"+String(syslog_priority)+">"+String(syslog_host)+" "+String(syslog_service_name)+": "+text;
  text.toCharArray(buf, sizeof(buf)-1);
  Udp.beginPacket(syslog_server, syslog_port);
  Udp.write(buf);
  Udp.endPacket();
}

bool basicAuthFailed() {
  if (strlen(www_username) > 0 && strlen(www_password) > 0) {
    if (!server.authenticate(www_username, www_password)) {
      server.requestAuthentication();
      return true;
    }
  }
  return false;    // This is good
}

bool handleFileRead(String path){
  DBG_OUTPUT_PORT.println("handleFileRead: " + path);
  if(path.equals(F("/"))) path = F("/static/index.htm");
  if(path.endsWith(F("/"))) path += F("index.htm");
  String contentType = getContentType(path);
  String pathWithGz = path + F(".gz");
  if(SPIFFS.exists(pathWithGz) || SPIFFS.exists(path)){
    if(SPIFFS.exists(pathWithGz))
      path += F(".gz");
    File file = SPIFFS.open(path, "r");
    server.sendHeader("Now", String(millis()));
    size_t sent = server.streamFile(file, contentType);
    file.close();
    return true;
  }
  return false;
}

void handleFileUpload(){
  if (basicAuthFailed()) return;
  if(server.uri() != F("/edit")) return;
  HTTPUpload& upload = server.upload();
  if(upload.status == UPLOAD_FILE_START){
    String filename = upload.filename;
    if(!filename.startsWith("/")) filename = "/"+filename;
    DBG_OUTPUT_PORT.println("handleFileUpload Name: " + filename);
    fsUploadFile = SPIFFS.open(filename, "w");
    filename = String();
  } else if(upload.status == UPLOAD_FILE_WRITE){
    //DBG_OUTPUT_PORT.println("handleFileUpload Data: " + upload.currentSize);
    if(fsUploadFile)
      fsUploadFile.write(upload.buf, upload.currentSize);
  } else if(upload.status == UPLOAD_FILE_END){
    if(fsUploadFile)
      fsUploadFile.close();
    DBG_OUTPUT_PORT.println("handleFileUpload Size: " + upload.totalSize);
  }
}

void handleFileDelete(){
  if (basicAuthFailed()) return;
  if(server.args() == 0) return server.send(500, F("text/plain"), F("BAD ARGS"));
  String path = server.arg(0);
  DBG_OUTPUT_PORT.println("handleFileDelete: " + path);
  if(path == "/")
    return server.send(500, F("text/plain"), F("BAD PATH"));
  if(!SPIFFS.exists(path))
    return server.send(404, F("text/plain"), F("FileNotFound"));
  SPIFFS.remove(path);
  server.send(200, F("text/plain"), "");
  path = String();
}

void handleFileCreate(){
  if (basicAuthFailed()) return;
  if(server.args() == 0)
    return server.send(500, "text/plain", "BAD ARGS");
  String path = server.arg(0);
  DBG_OUTPUT_PORT.println("handleFileCreate: " + path);
  if(path == "/")
    return server.send(500, "text/plain", "BAD PATH");
  if(SPIFFS.exists(path))
    return server.send(500, "text/plain", "FILE EXISTS");
  File file = SPIFFS.open(path, "w");
  if(file)
    file.close();
  else
    return server.send(500, "text/plain", "CREATE FAILED");
  server.send(200, "text/plain", "");
  path = String();
}

void handleFileList() {
  if (basicAuthFailed()) return;
  if(!server.hasArg("dir")) {server.send(500, "text/plain", "BAD ARGS"); return;}
  
  String path = server.arg("dir");
  DBG_OUTPUT_PORT.println("handleFileList: " + path);
  Dir dir = SPIFFS.openDir(path);
  path = String();

  String output = "[";
  while(dir.next()){
    File entry = dir.openFile("r");
    if (output != "[") output += ',';
    bool isDir = false;
    output += "{\"type\":\"";
    output += (isDir)?"dir":"file";
    output += "\",\"name\":\"";
    output += String(entry.name()).substring(1);
    output += "\"}";
    entry.close();
  }
  
  output += "]";
  server.send(200, "text/json", output);
}

void handleDoS(){
  if (basicAuthFailed()) return;
  drainD0();
  server.send(200, F("text/plain"), "");
  append_log(F("DoS mode set by API request."));
}

void handleRestart() {
  if (basicAuthFailed()) return;
  append_log(F("Restart requested by user."));
  server.send(200, "text/plain", "OK");
  ESP.restart();
}

void resetConfig(void) {
  if (millis() > 30000) return;
  if (digitalRead(CONF_RESET) == 0 & reset_pin_state == 1) {
    reset_pin_state = 0;
    config_reset_millis = millis();
  } else {
    reset_pin_state = 1;
    if (millis() > (config_reset_millis + 2000)) {
      append_log(F("Config reset by pin."));
      SPIFFS.remove(CONFIG_FILE);
      ESP.restart();
    }
  }
}

void auxChange(void) {
  volatile byte new_value = digitalRead(LED_SENSE);
  if (new_value == expect_aux) {
    last_aux = new_value;
    expect_aux = 2;
    return;
  }
  if (new_value != last_aux) {
    if (millis() - last_aux_change > 10) {
      last_aux_change = millis();
      last_aux = new_value;
      append_log("Aux changed to "+String(new_value));
    }
  }
}
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
void loop() {
  // Check for serial data
  /*
  if (DBG_OUTPUT_PORT.available() > 0 ) {
    incoming_byte = DBG_OUTPUT_PORT.read();
    DBG_OUTPUT_PORT.println(incoming_byte);
    delay(10);
  }
  */

  // Check for card reader data
  if(reader1_count >= CARD_LEN && (reader1_millis + 5 <= millis() || millis() < 10)) {
    fix_reader1_string();
    String name = grep_auth_file();
    if (name != "") {
      if (toggle_pin(LED_ASSERT)) {
        name += " enabled "+String(log_name);
      } else {
        name += " disabled "+String(log_name);
      }
      append_log(name);
      syslog(name);
    } else if (reader1_string == DoS_id) {
      drainD0();
      append_log("DoS mode enabled by control card");
    } else {
      append_log(reader1_string);
    }
    reader1_reset();
  }

  // Check for HTTP requests
  server.handleClient();
  ArduinoOTA.handle();

  /*
  // Blink LED for testing
  digitalWrite(LED_ASSERT, HIGH);
  delay(100);
  digitalWrite(LED_ASSERT, LOW);
  delay(4900);
  */

  // Standard delay
  delay(100);
}

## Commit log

2018-01-09 Repair case globbing by removing double-quotes
2021-08-09 Added schematic PDF
